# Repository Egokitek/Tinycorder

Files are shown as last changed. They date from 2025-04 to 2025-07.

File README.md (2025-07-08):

# Tinycorder (ES)

**(English below)**

## Un pequeño dispositivo multiuso con sensores

**Tinycorder** es un pequeño dispositivo multiuso que busca homenajear al mítico **tricorder** de la serie de ciencia ficción **Star Trek.**

Incluye varios sensores, asi como una pantalla de alta resolucion y bajo consumo que permite que lo usemos como badge electronico.

Es pequeño (75x85x10mm), ligero (70gr) y gasta muy poca energía.

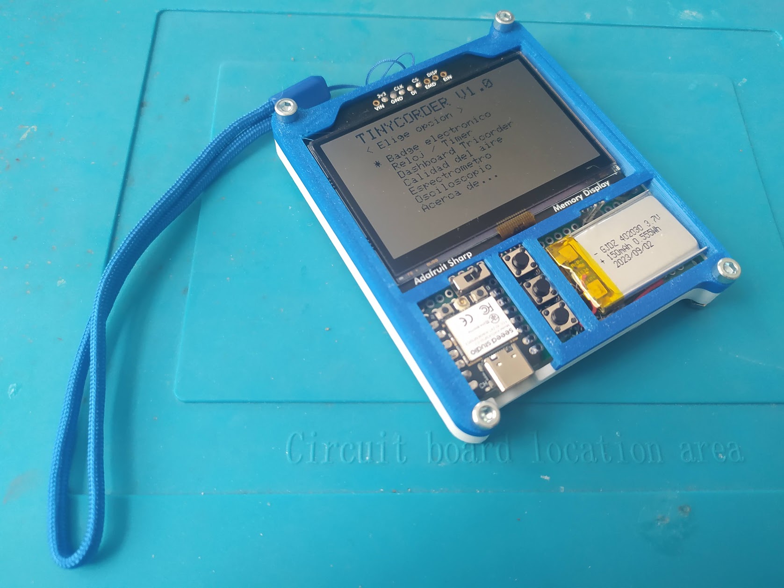
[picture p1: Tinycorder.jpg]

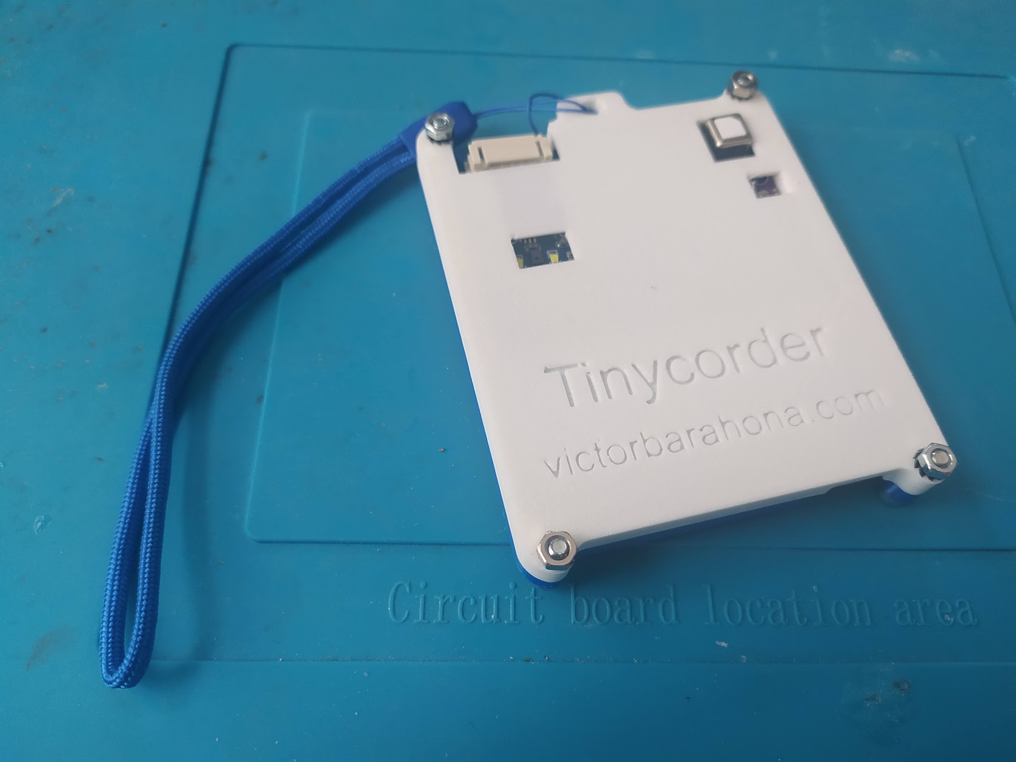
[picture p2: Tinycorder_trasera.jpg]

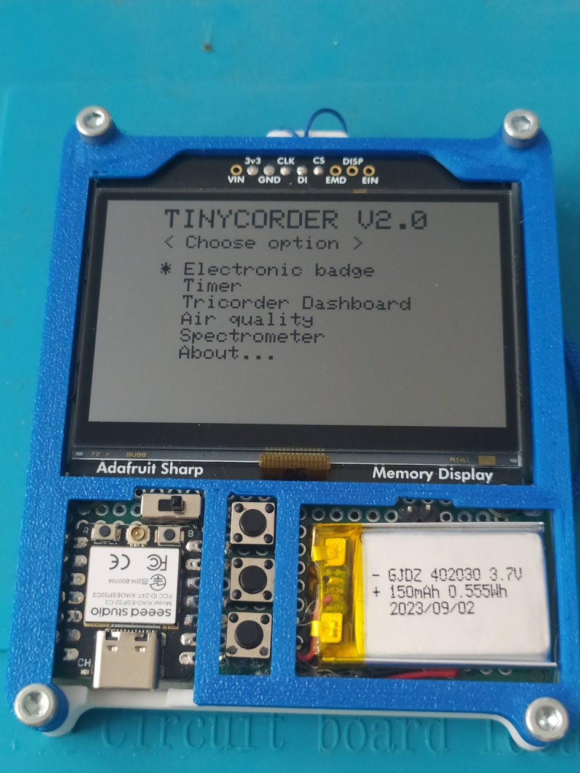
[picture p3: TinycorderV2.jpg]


## Características principales

- Chasis de dos piezas en PLA que se unen mediante 4 tornillos de M3x10.
- Incluye gancho para poderlo colgar del cuello o de la mano.
- MCU XIAO ESP32C3 de Seeed Studio.
- Batería Ion Litio de 150mAh.
- Interruptor de encendido y 3 pushbutton para interfaz (Up, Down, Enter).
- Pantalla Sharp Memory Display de 400x240px de Adafruit. Muy bajo consumo. 
- Sensor AS7341 para medición de luz en 7 bandas de visible y NIR (IR cercano).
- Sensor SCD40 para medición de calidad del aire y CO2.
- 2 pines libres accesibles desde frontal para medir señales analógicas.

## Algunas funciones ya en servicio

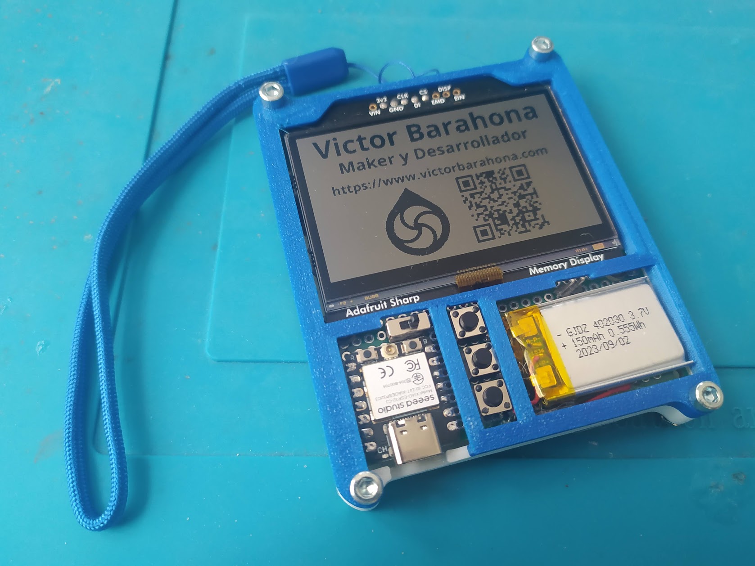
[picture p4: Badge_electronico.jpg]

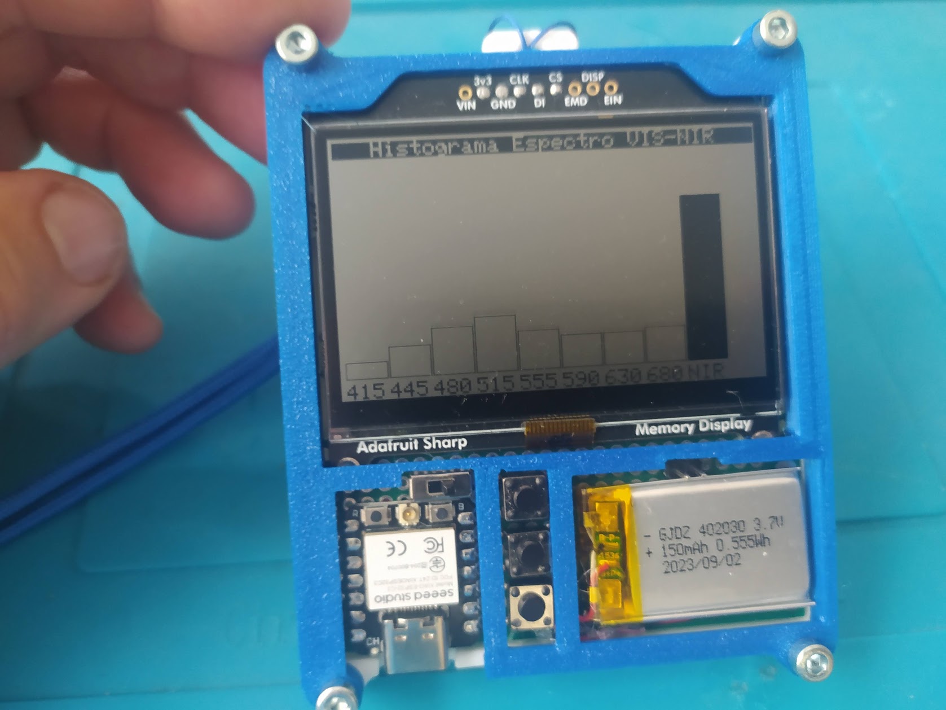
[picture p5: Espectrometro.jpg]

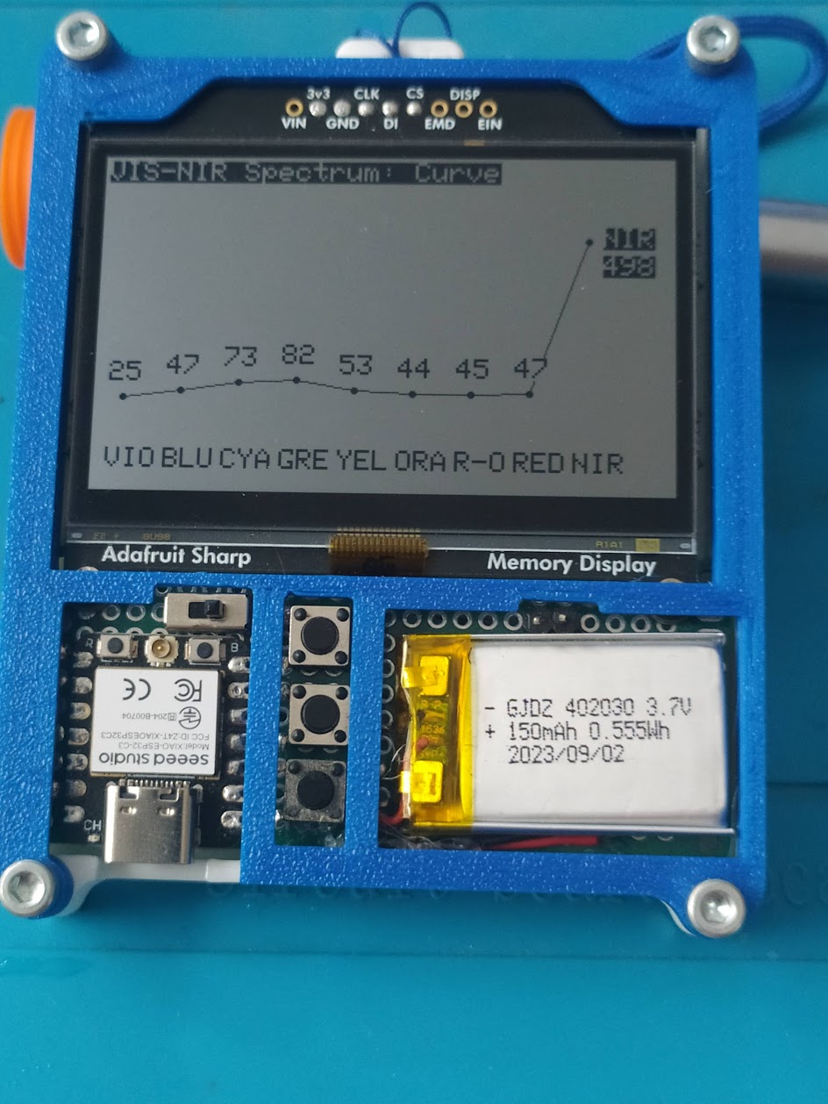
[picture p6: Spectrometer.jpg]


## Contenido de las carpetas

[**Montaje**](Montaje/README.md)

Proceso de montaje mediante fotos comentadas.

[**STLs**](STL/README.md)

Ficheros STL listos para imprimir.

[**SRC**](SRC/README.md)

Ficheros Arduino.

## Lista de componentes (BOM)

[BOM.xls](BOM.xlsx)

## Autor

Me llamo **Victor Barahona** y soy un ingeniero que ha sabido adaptarse a diferentes olas tecnológicas a lo largo de 30 años de carrera profesional. Tanto en el sector público como privado, tanto por cuenta ajena como de autónomo y emprendedor.

He trabajado en enseñanza, industria de automoción, telefonía móvil, impresión 3D, desarrollo de proyectos opensource y actualmente estoy en la empresa **I+Med** donde investigo en sistemas embebidos y Bioelectrónica.

Tengo varios hobbies, entre ellos la Permacultura. Soy también un maker entusiasta y construyo cosas como impresoras 3D o ARSandbox.

**Hago este tipo de proyectos en mi tiempo libre. Si te gustan y deseas apoyar que siga con ellos puedes donar o aportar en ko-fi:**



[**Mi cuenta Github**](https://github.com/Egokitek)

[Mi sitio web **www.victorbarahona.com**](http://www.victorbarahona.com)

## Créditos

Star Trek me inspiró para realizar este proyecto pero el diseño es totalmente propio.

## Licencia

GPL3.0

## Posibles mejoras

- Monitorear tension de batería y mostrarla mediante un indicador.
- Añadir funciones pendientes como tester/osciloscopio
- Nuevas funciones que se me vayan ocurriendo.

## Version 2 (actualizada el 6 de Julio de 2025)

**Se completa el código con los siguientes cambios:**

- Se completa la funcion de timer, permite ajustar bloques de 5 hasta 120 min. En el bloque de 25min aparece un mensaje de "Pomodoro Timer !". Al activar comienza cuenta atras y al terminar avisa con un rotulo intermitente en pantalla.
- Se completa el menu de Dashboard, que muestra medidas de CO2, temp y humedad en forma de histograma, con medidas cada 5 min hasta un total de 24 por cada variable. El tiempo entre muestras se puede cambiar en firmware para que tome un tiempo mas amplio de muestreo total.
- El menu "Calidad del aire" presenta medidas de CO2, temperatura y humedad cada 5 segundos de forma continua, hasta que vuelvas al menu principal.
- El menú "espectrómetro ya funcionaba pero se ha mejorado. Ahora puede mostrar el espectro en forma de histograma, lineas o numérico, se puede cambiar entre cualquiera de ellos o volver al menu principal.
- El menú "Acerca de" se ha mejorado en estética y presenta información básica.
- Se ha eliminado por el momento la función de osciloscopio. Quizás se aborde en el futuro.

**Cambios pendientes:**

- Añadir un buzzer pequeño para dar sonido al dispositivo.
- Añadir un sensor de tiempo de vuelo para medir distancia y quizas generar una especie de "sonar".
- Optimizar el consumo jugando mejor con los procesos de deep sleep.
- Opción de activar/desactivar LED para linterna, usando los que lleva el sensor de espectrómetro.
- Control de tensión de batería para ver autonomía en pantalla.
- Probar con otras pantallas mas economicas y rediseñar el hardware. La Sharp es muy buena pero es algo cara.
- **Importante** crear la PCB. Ahora es una perfboard ya que es un prototipo.
- ¿ Que mas .....?

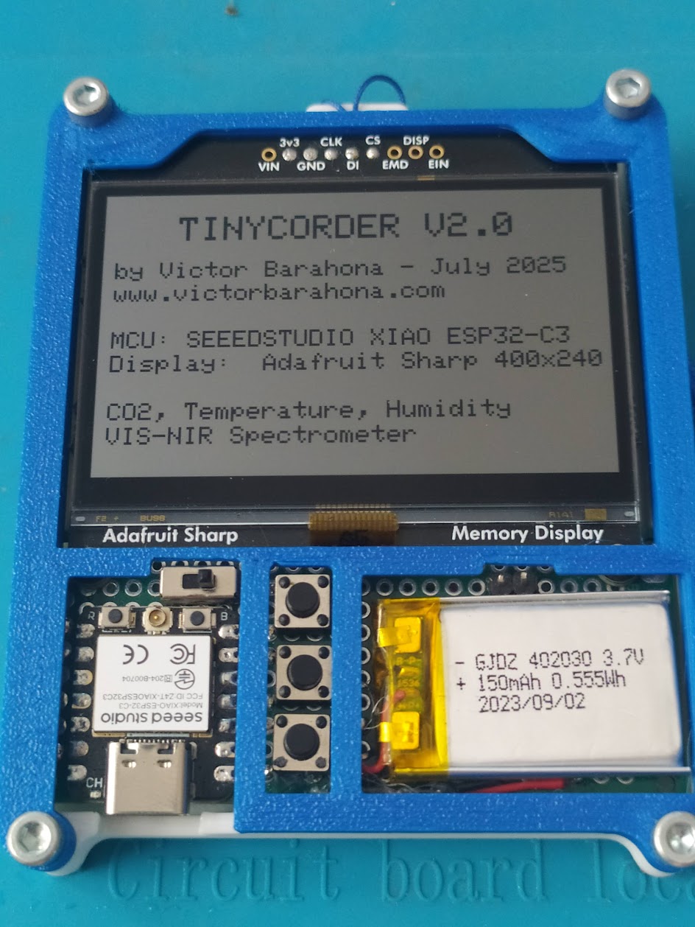
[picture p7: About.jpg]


---

# Tinycorder (EN)

## A small multi-purpose device with sensors

**Tinycorder** is a small multi-purpose device that pays homage to the legendary **tricorder** from the science fiction series **Star Trek.**

It includes several sensors, as well as a high-resolution, low-power display that allows it to be used as an electronic badge.

It is small (75x85x10mm), lightweight (70g), and consumes very little power.

## Main features

- Two-piece PLA chassis joined by 4 M3x10 screws.
- Includes a hook to hang it from your neck or hand.
- Seeed Studio XIAO ESP32C3 MCU.
- 150mAh Lithium-Ion battery.
- Power switch and 3 pushbuttons for interface (Up, Down, Enter).
- Adafruit Sharp Memory Display 400x240px. Very low power consumption.
- AS7341 sensor for measuring light in 7 visible and NIR (near IR) bands.
- SCD40 sensor for air quality and CO2 measurement.
- BMP280 sensor for temperature, humidity, and pressure measurement.
- 2 free pins accessible from the front to measure analog signals.

## Some functions already in service

Cyberdeck PICO8

## Folder contents

[**Assembly**](Montaje/README.md)

Assembly process with commented photos.

[**STLs**](STL/README.md)

Ready-to-print STL files.

[**SRC**](SRC/README.md)

Arduino files.

## Bill of Materials (BOM)

[BOM.xls](BOM.xlsx)

## Author

My name is **Victor Barahona** and I am an engineer who has adapted to different technological waves over 30 years of professional career. Both in the public and private sectors, as an employee, freelancer, and entrepreneur.

I have worked in education, automotive industry, mobile telephony, 3D printing, open source project development, and I am currently at **I+Med** where I research embedded systems and Bioelectronics.

I have several hobbies, including Permaculture. I am also an enthusiastic maker and build things like 3D printers or ARSandbox.

**I do these kinds of projects in my free time. If you like them and want to support me to continue, you can donate or contribute on ko-fi:**



[**My Github account**](https://github.com/Egokitek)

[My website **www.victorbarahona.com**](http://www.victorbarahona.com)

## Credits

Star Trek inspired me to make this project but the design is entirely my own.

## License

GPL3.0

## Possible improvements

- Monitor battery voltage and display it with an indicator.
- Add pending functions such as tester/oscilloscope
- New functions as they occur to me.

## Version 2 (updated July 6, 2025)

**The code is completed with the following changes:**

- The timer function is completed, allowing you to set blocks from 5 to 120 min. In the 25min block, a "Pomodoro Timer!" message appears. When activated, it starts a countdown and, when finished, notifies with a flashing label on the screen.
- The Dashboard menu is completed, showing CO2, temp, and humidity measurements as a histogram, with measurements every 5 min up to a total of 24 for each variable. The time between samples can be changed in firmware to take a longer total sampling time.
- The "Air Quality" menu presents CO2, temperature, and humidity measurements every 5 seconds continuously, until you return to the main menu.
- The "Spectrometer" menu was already working but has been improved. Now it can display the spectrum as a histogram, lines, or numeric; you can switch between any of them or return to the main menu.
- The "About" menu has been improved in appearance and presents basic information.
- The oscilloscope function has been removed for now. It may be addressed in the future.

**Pending changes:**

- Add a small buzzer to give sound to the device.
- Add a time-of-flight sensor to measure distance and perhaps generate a kind of "sonar".
- Optimize power consumption by better managing deep sleep processes.
- Option to enable/disable LED for flashlight, using those on the spectrometer sensor.
- Battery voltage control to see autonomy on screen.
- Try other, more economical displays and redesign the hardware. The Sharp is very good but somewhat expensive.
- **Important** create the PCB. It is currently a perfboard as it is a prototype.
- What else...?

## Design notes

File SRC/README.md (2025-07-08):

# Código Arduino
## (English below)

**En esta carpeta se contienen los ficheros necesarios del código Arduino.**

Contiene el fichero .ino principal y dos ficheros auxiliares:

- Badges.h
- Badges.cpp

Ambos sirven para la conversión del badge de jpg a código entendible por Arduino.

---

## Arduino Code

**This folder contains the necessary Arduino code files.**

It includes the main .ino file and two auxiliary files:

- Badges.h
- Badges.cpp

Both are used for converting the badge from jpg to code understandable by Arduino.

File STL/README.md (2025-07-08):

# STLs
## (English below)

**En esta carpeta se contienen los ficheros STL necesarios**

Puedes verlos con el visualizador integrado en Github o bien mediante programas como Cura, Repetier etc.

Contiene dos ficheros, la parte superior e inferior de la carcasa, que se unen mediante 4 tornillos de M3x10.

---

## STL Files

This folder contains the necessary STL files.

You can view them with the integrated viewer on Github or with programs such as Cura, Repetier, etc.

It contains two files, the top and bottom parts of the case, which are joined together with 4 M3x10 screws.

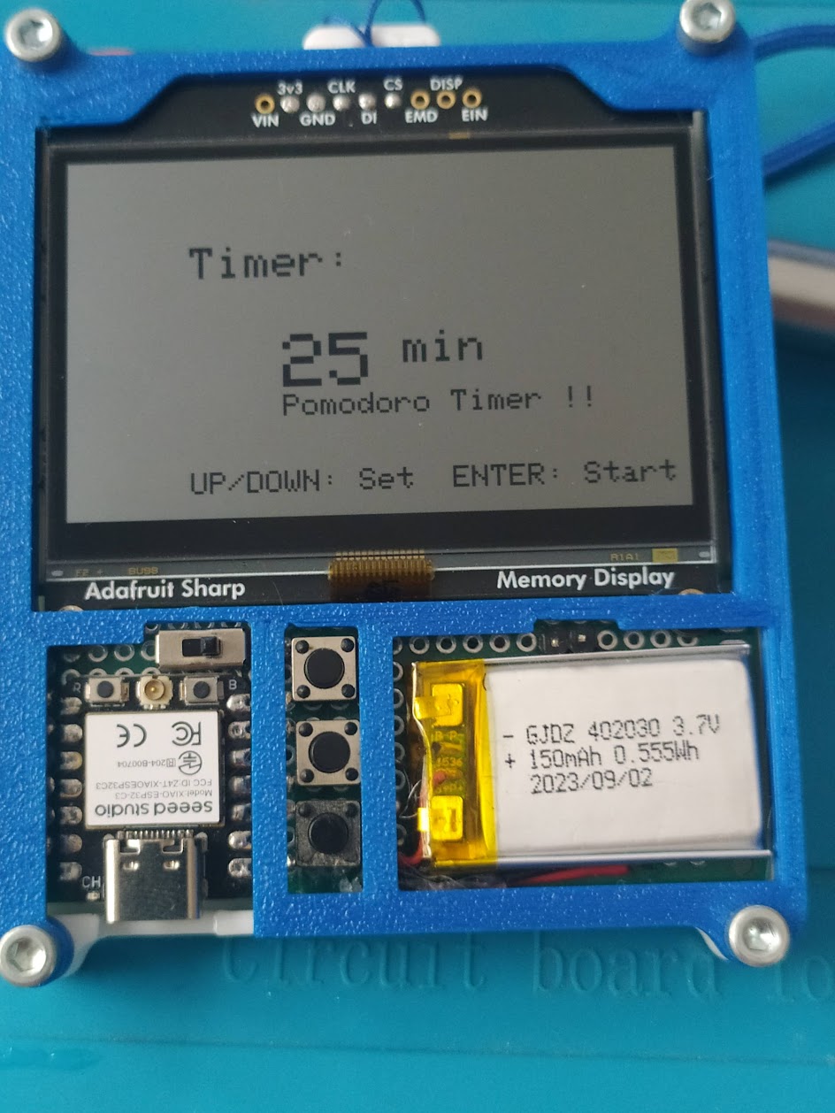
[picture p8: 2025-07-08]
Pomodoro.jpg

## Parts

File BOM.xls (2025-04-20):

Descripción | Componente | Cantidad | Coste EUR | Proveedor | Observaciones
Interruptor encendido | Toggle Switch | 1 | 0.05 | Amazon | Lote de 150 a 8eur
Li Ion 150mAh | LIPO-150mAh | 1 | Reciclada |  | Reciclada de teclado bluetooth
Pantalla Adafruit LCD | LCD 400x240px | 1 | 35 | Digikey | Sharp Memory Display
MCU ESP32C3 | XIAO ESP32C3 | 1 | 5 | Digikey | SEEED STUDIO XIAO ESP32C3
Pushbutton | Pushbutton | 3 | 0.05 | Amazon | Lote de 100 a unos 5eur
Sensor Temp, Hr, presion | BMP280 | 1 | 5 | Aliexpress
Sensor CO2 | SCD40 | 1 | 12 | Aliexpress
Sensor luz 8 bandas | AS7341 | 1 | 20 | Aliexpress

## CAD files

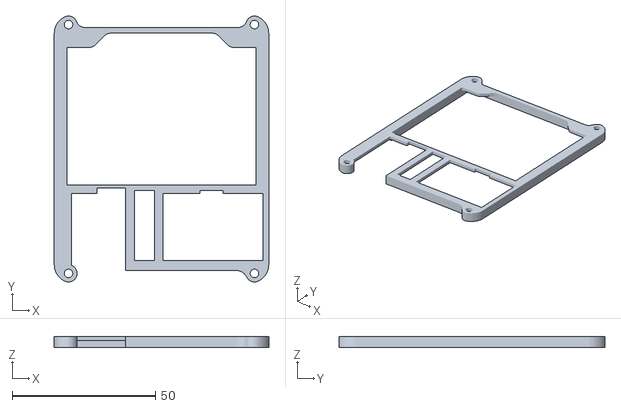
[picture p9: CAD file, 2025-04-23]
STL/Tinycorder Top.stl
75.0 x 93.0 x 4.00

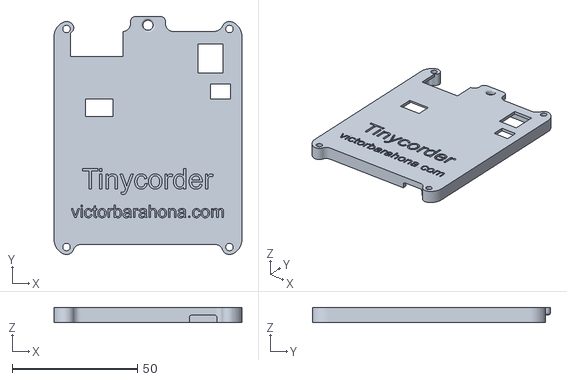
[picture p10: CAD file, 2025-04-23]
STL/Tinycorder Bottom.stl
75.0 x 95.0 x 6.00

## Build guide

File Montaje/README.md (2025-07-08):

# Montaje de Tinycorder
# (English below)

## Esquema del dispositivo:

ATENCION: Algunos componentes no se muestran como son realmente ya que Fritzing no los contiene en las librerías. Y puede haber algun error en la nomenclatura de los pines. Tomar la información de este montaje con precaución.

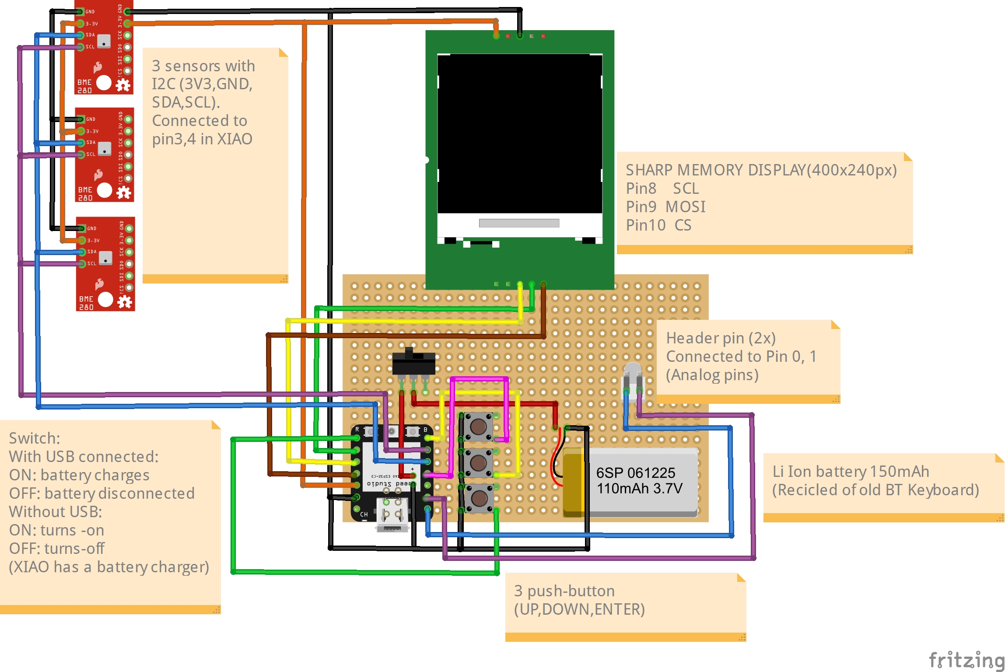
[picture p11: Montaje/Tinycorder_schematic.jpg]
Esquemático


## Montaje del dispositivo:

En esta imagen vemos los componentes que vamos a utilizar. La pantalla usa el bus SPI y los sensores el I2C, de solo dos pines.

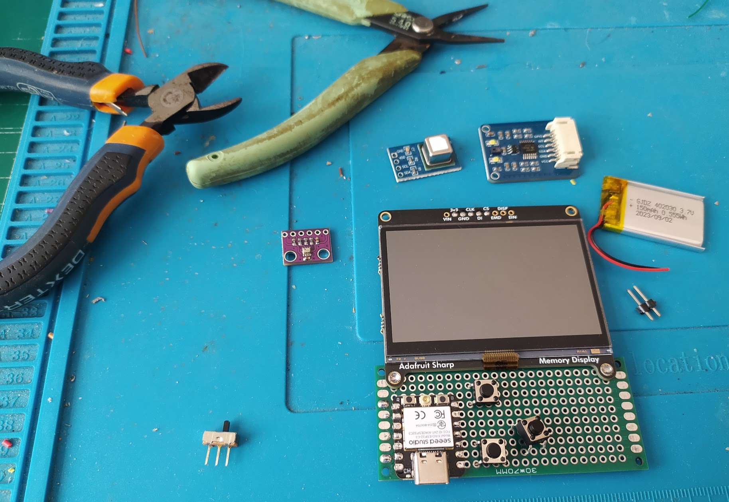
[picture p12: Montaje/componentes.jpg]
Componentes


Procedemos a soldar los componentes entre si.

En la perfboard soldamos el MCU, switch, 3 pushbutton y header de dos puntas. Para el XIAO alinear bien de tal forma que sus dos pad de bateria queden accesibles desde abajo, ya que aplicaremos una gota de soldadura y debe servir para que el circuito de control de la bateria funcione bien. Lo sabremos si al conectar el puerto USB tenemos unos 4V en esas dos conexiones. Si no lo tenemos hay que repasar la soldadura.

La perfboard la unimos al display con soldadura (tiene zonas metalicas donde el estaño agarra bien. Tambien puede hacerse con cola termofusible).

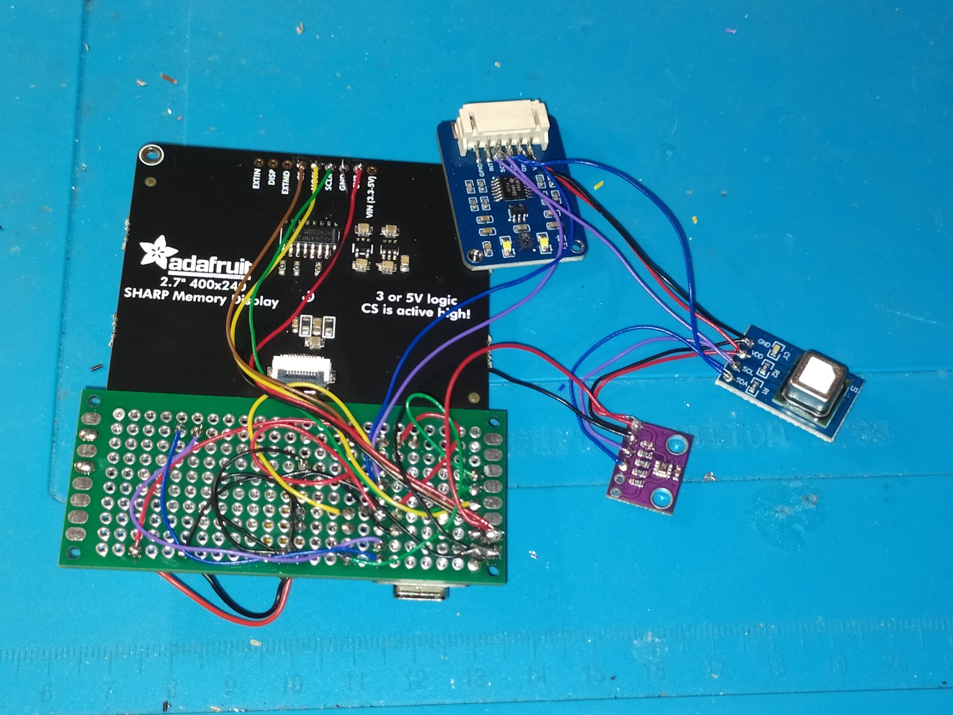
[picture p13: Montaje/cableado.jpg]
Cableado


La batería la pegaremos con cola termofusible, igualmente los sensores, aprovechando el espacio libre en la parte trasera del display que es plano.

**ATENCION: Diseñé las piezas en PLA después de este punto con las medidas tal y como coloqué los componentes. Si construyes una copia tendrás que hacerlo al revés. Imprimir las piezas y usarlas como guía para pegar os sensores, si no no te cabrán correctamente.**

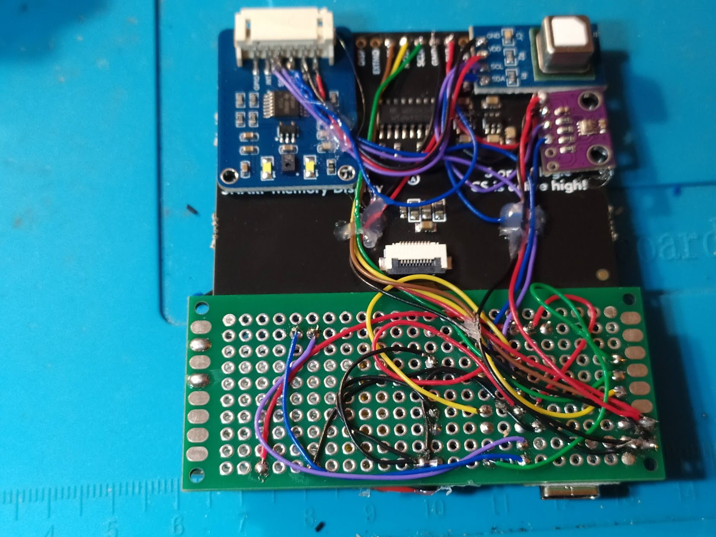
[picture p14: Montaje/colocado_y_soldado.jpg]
Montaje y soldadura


Una vez montado y cargado el software vemos el aspecto que tiene.

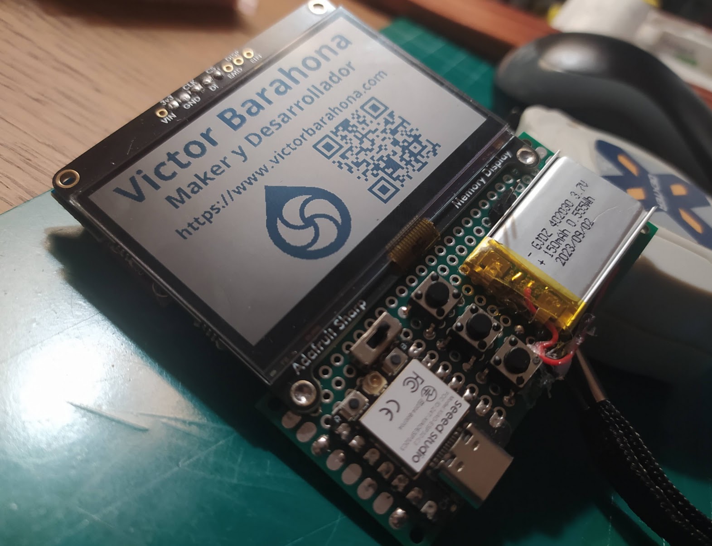
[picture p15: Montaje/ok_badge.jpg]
Prueba Badge


Y aquí como espectrómetro numérico, los valores se ven bajos porque el sensor está contra la mesa y no recibe luz.

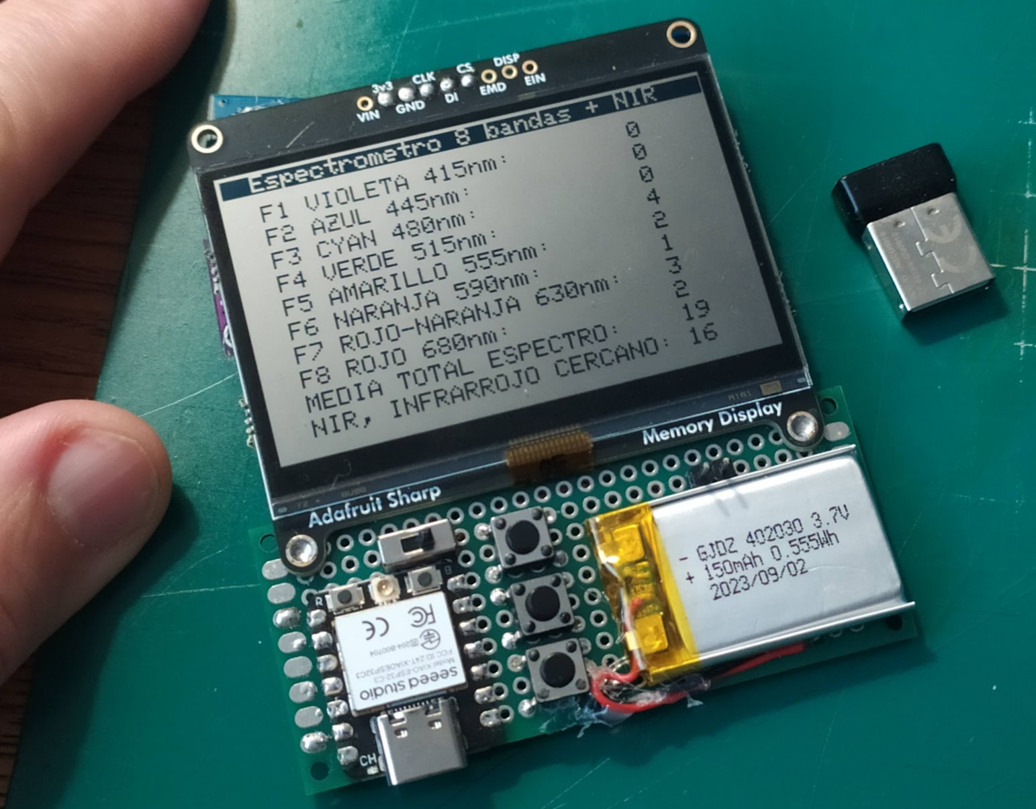
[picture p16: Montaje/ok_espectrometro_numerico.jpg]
Espectrómetro numérico


***

## Tinycorder Assembly

## Device schematic:

WARNING: Some components are not shown as they really are because Fritzing does not include them in its libraries. There may also be some errors in pin naming. Take the information from this assembly with caution.

Esquemático

## Device assembly:

In this image we see the components we are going to use. The display uses the SPI bus and the sensors use I2C, which only requires two pins.

Componentes

We proceed to solder the components together.

On the perfboard, solder the MCU, switch, 3 pushbuttons, and a two-pin header. For the XIAO, align it so that its two battery pads are accessible from below, as we will apply a drop of solder and it must allow the battery control circuit to work properly. We will know it works if, when connecting the USB port, we have about 4V on those two connections. If not, check the soldering.

Join the perfboard to the display with solder (it has metallic areas where the tin adheres well. It can also be done with hot glue).

Cableado

Glue the battery with hot glue, as well as the sensors, taking advantage of the free space on the back of the display, which is flat.

**WARNING: I designed the PLA parts after this point with the measurements as I placed the components. If you build a copy, you will have to do it the other way around: print the parts and use them as a guide to glue the sensors, otherwise they will not fit correctly.**

Montaje y soldadura

Once assembled and the software loaded, this is how it looks.

Prueba Badge

And here as a numeric spectrometer, the values appear low because the sensor is facing the table and does not receive light.

Espectrómetro numérico

***

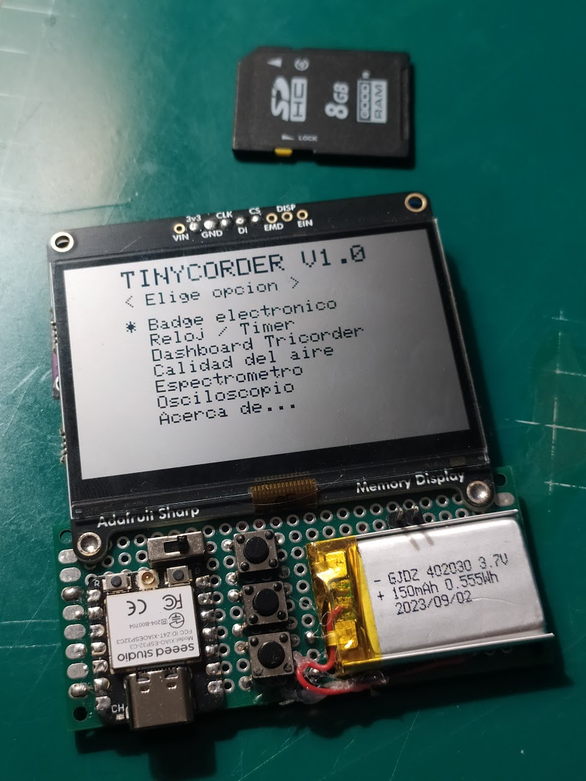
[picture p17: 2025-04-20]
Montaje/IMG_20250325_202723.jpg

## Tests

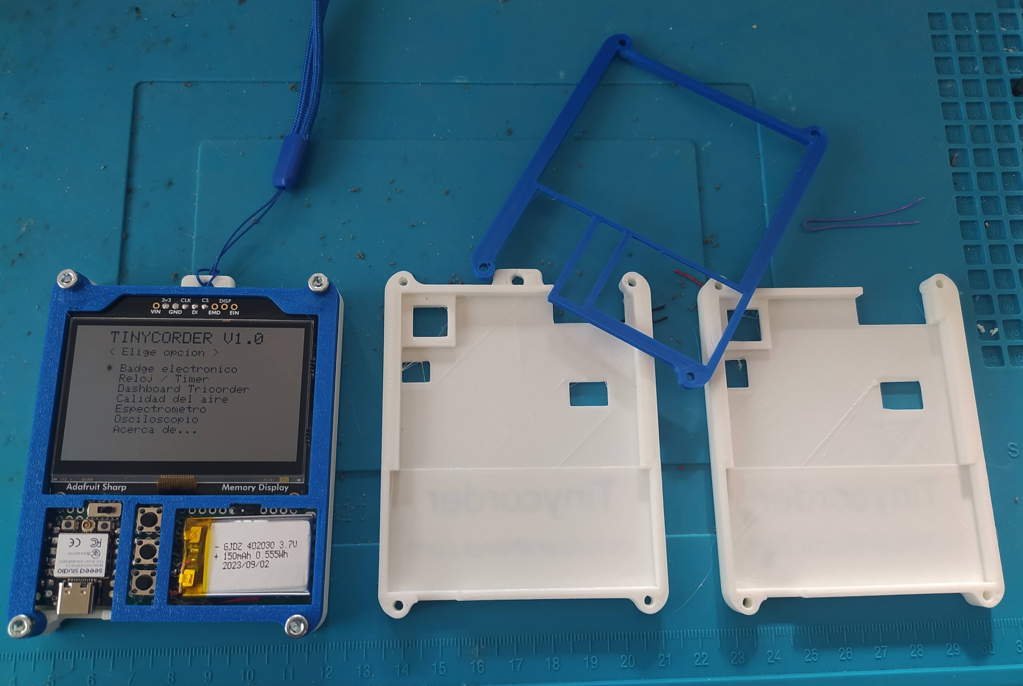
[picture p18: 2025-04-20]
Montaje/pruebas_carcasa.jpg

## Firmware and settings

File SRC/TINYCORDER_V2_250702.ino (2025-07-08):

///////////////////////////////////////////////////////////
///                  TINYCORDER V2.0                    ///
///////////////////////////////////////////////////////////
///                    MAIN PROGRAM                     ///
///////////////////////////////////////////////////////////
///            Victor Barahona - July 2025              ///
///               www.victorbarahona.com                ///
///////////////////////////////////////////////////////////

/*  TINYCORDER: UN TRICORDER BASADO EN EL ADAFRUIT SHARP MEMORY DISPLAY DE 400x240px */

#include <Arduino.h>
#include <esp_sleep.h>
#include <Adafruit_SharpMem.h>  //Librería especifica Pantalla 400x240 de Adafruit
#include <Adafruit_AS7341.h>    //Sensor espectrometro
#include "Adafruit_GFX.h"       //Librería gráfica Adafruit
#include <SPI.h>                //La pantalla necesita bus SPI
#include <Wire.h>               //Para tareas que requieren bus I2C
#include <SensirionI2CScd4x.h>  //Libreria sensor CO2, temp, humedad


#include "Badges.h"  //Contiene los badges que voy implementando de forma personalizada

// any pins can be used
#define SHARP_SCK 8
#define SHARP_MOSI 9
#define SHARP_SS 10

#define ANCHO 400
#define ALTO 240
#define BLACK 0
#define WHITE 1

//Adafruit_SharpMem display(SHARP_SCK, SHARP_MOSI, SHARP_SS, 144, 168);
Adafruit_SharpMem display(SHARP_SCK, SHARP_MOSI, SHARP_SS, ANCHO, ALTO);
int minorHalfSize;  // 1/2 of lesser of display width or height

//Instanciar clase sensor CO2
SensirionI2CScd4x scd4x;

void printUint16Hex(uint16_t value) {
  Serial.print(value < 4096 ? "0" : "");
  Serial.print(value < 256 ? "0" : "");
  Serial.print(value < 16 ? "0" : "");
  Serial.print(value, HEX);
}

void printSerialNumber(uint16_t serial0, uint16_t serial1, uint16_t serial2) {
  Serial.print("Serial: 0x");
  printUint16Hex(serial0);
  printUint16Hex(serial1);
  printUint16Hex(serial2);
  Serial.println();
}

// --- PARAMETRIZACIÓN DE IDIOMA --- // --- LANGUAGE PARAMETERIZATION ---
enum Idioma { ESPANOL, INGLES }; // Idioma actual // Current language
Idioma idiomaActual = INGLES; // Cambia a ESPANOL si lo prefieres // Change to ESPANOL if you prefer
void setIdioma(Idioma idioma); // Prototipo necesario para evitar error de compilación // Prototype needed to avoid compilation error

//Botones para controlar el dispositivo // Buttons to control the device
#define BUTTON_UP 5       // Cable Rojo, pin 3, gpio 5 // Red wire, pin 3, gpio 5
#define BUTTON_DOWN 21    // Cable amarillo, pin 6, gpio 21 // Yellow wire, pin 6, gpio 21
#define BUTTON_ENTER 20   // Cable verde, pin 7, gpio 20 // Green wire, pin 7, gpio 20
#define DEBOUNCE_TIME 50  // Tiempo de debounce en ms // Debounce time in ms

unsigned long lastDebounceTimeUP = 0;
unsigned long lastDebounceTimeDOWN = 0;
unsigned long lastDebounceTimeENTER = 0;
bool lastStateUP = HIGH;
bool lastStateDOWN = HIGH;
bool lastStateENTER = HIGH;
bool currentStateUP = HIGH;
bool currentStateDOWN = HIGH;
bool currentStateENTER = HIGH;

const char *menus_es[] = { "Badge electronico", "Timer", "Dashboard Tricorder", "Calidad del aire", "Espectrometro", "Acerca de..." }; // Menú en español // Menu in Spanish
const char *menus_en[] = { "Electronic badge", "Timer", "Tricorder Dashboard", "Air quality", "Spectrometer", "About..." }; // Menú en inglés // Menu in English
const char **menus = menus_en; // Por defecto inglés // Default to English
const int totalMenus = 6;
int menuIndex = 0;
bool menuSelected = false;
unsigned long lastButtonPress = 0;

/* Definición de la clase para el sensor AS7341, espectrometro de 8 bandas mas NIR */
/* Definition of the class for the AS7341 sensor, 8-band spectrometer plus NIR */
Adafruit_AS7341 as7341;

// --- DASHBOARD: HISTÓRICO DE 24 MEDIDAS ---
#define DASHBOARD_HISTORY 24
unsigned long dashboard_interval_ms = 5UL * 60UL * 1000UL; // Intervalo de muestreo en ms (por defecto 5 minutos)
uint16_t co2_history[DASHBOARD_HISTORY] = {0};
float temp_history[DASHBOARD_HISTORY] = {0};
float hum_history[DASHBOARD_HISTORY] = {0};
uint8_t dashboard_index = 0;
uint8_t dashboard_count = 0;
unsigned long dashboard_last_update = 0;

void setup() {
  Serial.begin(115200);
  display.begin();
  Wire.begin();

  //while (!Serial) {
  //  delay(100);
  //}

  uint16_t error;
  char errorMessage[256];
  scd4x.begin(Wire);

  // stop potentially previously started measurement // Detener medición previa si existe
  error = scd4x.stopPeriodicMeasurement();
  if (error) {
    Serial.print("Error trying to execute stopPeriodicMeasurement(): ");
    errorToString(error, errorMessage, 256);
    Serial.println(errorMessage);
  }

  uint16_t serial0;
  uint16_t serial1;
  uint16_t serial2;
  error = scd4x.getSerialNumber(serial0, serial1, serial2);
  if (error) {
    Serial.print("Error trying to execute getSerialNumber(): ");
    errorToString(error, errorMessage, 256);
    Serial.println(errorMessage);
  } else {
    printSerialNumber(serial0, serial1, serial2);
  }

  // Start Measurement // Iniciar medición
  error = scd4x.startPeriodicMeasurement();
  if (error) {
    Serial.print("Error trying to execute startPeriodicMeasurement(): ");
    errorToString(error, errorMessage, 256);
    Serial.println(errorMessage);
  }

  Serial.println("Waiting for first measurement... (5 sec)"); // Esperando primera medición

  //setup de botones y su tiempo de rebote // Button setup and debounce time
  pinMode(BUTTON_UP, INPUT_PULLUP);     // Activa la resistencia pull-up interna // Enable internal pull-up resistor
  pinMode(BUTTON_DOWN, INPUT_PULLUP);   // Activa la resistencia pull-up interna // Enable internal pull-up resistor
  pinMode(BUTTON_ENTER, INPUT_PULLUP);  // Activa la resistencia pull-up interna // Enable internal pull-up resistor

  display.clearDisplay();  // clears the screen and buffer // Limpia la pantalla y el buffer

  // Several shapes are drawn centered on the screen.  Calculate 1/2 of
  // lesser of display width or height, this is used repeatedly later.
  // Varias formas se dibujan centradas en la pantalla. Calcula 1/2 del menor de ancho o alto, se usa repetidamente.
  minorHalfSize = min(display.width(), display.height()) / 2;

  if (!as7341.begin()) {
    Serial.println("Could not find AS7341"); // No se pudo encontrar el AS7341
    while (1) { delay(10); }
  }

  as7341.setATIME(100);
  as7341.setASTEP(999);
  as7341.setGain(AS7341_GAIN_256X);

  drawMenu();
}

void loop() {
  display.setRotation(0);
  showMenu();
}


void checkButtons() {
  unsigned long currentMillis = millis();

  // --- Debounce para BUTTON_UP  ---
  bool readingUP = digitalRead(BUTTON_UP);
  if (readingUP != lastStateUP) {
    lastDebounceTimeUP = currentMillis;
  }
  if ((currentMillis - lastDebounceTimeUP) > DEBOUNCE_TIME) {
    if (readingUP == LOW && currentStateUP == HIGH) {
      menuIndex = (menuIndex - 1 + totalMenus) % totalMenus;
      drawMenu();
    }
    currentStateUP = readingUP;
  }
  lastStateUP = readingUP;

  // --- Debounce para BUTTON_DOWN  ---
  bool readingDOWN = digitalRead(BUTTON_DOWN);
  if (readingDOWN != lastStateDOWN) {
    lastDebounceTimeDOWN = currentMillis;
  }
  if ((currentMillis - lastDebounceTimeDOWN) > DEBOUNCE_TIME) {
    if (readingDOWN == LOW && currentStateDOWN == HIGH) {
      menuIndex = (menuIndex + 1) % totalMenus;
      drawMenu();
    }
    currentStateDOWN = readingDOWN;
  }
  lastStateDOWN = readingDOWN;

  // --- Debounce para BUTTON_ENTER  ---
  bool readingENTER = digitalRead(BUTTON_ENTER);
  if (readingENTER != lastStateENTER) {
    lastDebounceTimeENTER = currentMillis;
  }
  if ((currentMillis - lastDebounceTimeENTER) > DEBOUNCE_TIME) {
    if (readingENTER == LOW && currentStateENTER == HIGH) {
      executeTask(menuIndex);
      drawMenu(); // Volver al menú en la misma posición
    }
    currentStateENTER = readingENTER;
  }
  lastStateENTER = readingENTER;
}

void drawMenu() {
  display.clearDisplay();
  display.setTextSize(3);
  display.setTextColor(BLACK);
  display.setCursor(60, 10);
  display.println("TINYCORDER V2.0");
  display.setCursor(60, 40);
  display.setTextSize(2);
  display.println(idiomaActual == ESPANOL ? "< Elige opcion >" : "< Choose option >");

  for (int i = 0; i < totalMenus; i++) {
    display.setCursor(60, 70 + (i * 18));  // Espaciado vertical entre opciones

    if (i == menuIndex) {
      display.print("* ");  // Asterisco para la opción seleccionada
    } else {
      display.print("  ");  // Espacio en las demás opciones
    }

    display.println(menus[i]);  // Mostrar nombre del menú
  }

  display.refresh();
  delay(50);
}

// --- PARAMETRIZACIÓN DE IDIOMA ---
//enum Idioma { ESPANOL, INGLES };
//Idioma idiomaActual = INGLES; // Cambia a ESPANOL si lo prefieres
void setIdioma(Idioma idioma) {
  idiomaActual = idioma;
  menus = (idioma == ESPANOL) ? menus_es : menus_en;
}

void executeTask(int index) {
  display.clearDisplay();
  display.setCursor(60, 200);
  display.setTextSize(1);
  display.setTextColor(BLACK);

  switch (index) {
    case 0:
      badge();
      break;
    case 1:
      timer();
      break;
    case 2:
      dashboard();
      break;
    case 3:
      calidad_aire();
      break;
    case 4:
      espectrometro();
      break;
    case 5:
      acercade();
      break;
  }

  display.refresh();
  delay(2000);  // Mantener el mensaje 2 segundos antes de volver al menú
}



void badge() {
  display.setTextColor(BLACK);
  //Muestra Badge personal
  display.drawBitmap(0, 0, vj_personal_badge, 400, 240, WHITE, BLACK);
  display.refresh();
  esp_deep_sleep_start();

}


// --- MENÚ ESPECTRÓMETRO: SELECCIÓN DIRECTA ---
void espectrometro() {
  int modo = 0;
  bool seleccionando = true;
  // Esperar a que todos los botones estén soltados antes de mostrar el menú
  while (digitalRead(BUTTON_UP) == LOW || digitalRead(BUTTON_DOWN) == LOW || digitalRead(BUTTON_ENTER) == LOW) {
    delay(10);
  }
  while (seleccionando) {
    display.clearDisplay();
    display.setTextSize(3);
    display.setCursor(60, 40);
    display.setTextColor(BLACK);
    display.println("Spectrometer:");
    display.setTextSize(2);
    display.setCursor(60, 90);
    display.print(modo == 0 ? "> " : "  "); display.println("Histogram");
    display.setCursor(60, 120);
    display.print(modo == 1 ? "> " : "  "); display.println("Curve");
    display.setCursor(60, 150);
    display.print(modo == 2 ? "> " : "  "); display.println("Data");
    display.refresh();
    // Navegación
    bool salir = false;
    while (!salir) {
      if (digitalRead(BUTTON_UP) == LOW) { modo = (modo + 2) % 3; delay(200); salir = true; }
      else if (digitalRead(BUTTON_DOWN) == LOW) { modo = (modo + 1) % 3; delay(200); salir = true; }
      else if (digitalRead(BUTTON_ENTER) == LOW) { delay(200); seleccionando = false; salir = true; }
      delay(10);
    }
    // Esperar a que se suelten todos los botones antes de permitir otra navegación
    while (digitalRead(BUTTON_UP) == LOW || digitalRead(BUTTON_DOWN) == LOW || digitalRead(BUTTON_ENTER) == LOW) {
      delay(10);
    }
  }
  // Ejecutar modo seleccionado
  switch (modo) {
    case 0: espectro_histograma(); break;
    case 1: espectro_grafica(); break;
    case 2: espectro_numerico(); break;
  }
}

// --- TIMER: AJUSTE Y CUENTA ATRÁS ---
void timer() {
  int minutos = 5;
  bool ajustando = true;
  // Esperar a que todos los botones estén soltados antes de mostrar el menú
  while (digitalRead(BUTTON_UP) == LOW || digitalRead(BUTTON_DOWN) == LOW || digitalRead(BUTTON_ENTER) == LOW) {
    delay(10);
  }
  while (ajustando) {
    display.clearDisplay();
    display.setTextSize(3);
    display.setCursor(80, 60);
    display.setTextColor(BLACK);
    display.print(idiomaActual == ESPANOL ? "Temporizador:" : "Timer:");
    display.setCursor(140, 120);
    display.setTextSize(5);
    display.print(minutos);
    display.setTextSize(3);
    display.print(" min");
    if (minutos == 25) {
      display.setTextSize(2);
      display.setCursor(140, 160);
      display.setTextColor(BLACK);
      display.print("Pomodoro Timer !!");
    }
    display.setTextSize(2);
    display.setCursor(80, 210);
    display.print(idiomaActual == ESPANOL ? "UP/DOWN: Ajustar  ENTER: Iniciar" : "UP/DOWN: Set  ENTER: Start");
    display.refresh();
    // Ajuste de minutos
    bool salir = false;
    while (!salir) {
      if (digitalRead(BUTTON_UP) == LOW) {
        minutos += 5;
        if (minutos > 120) minutos = 5;
        delay(200);
        salir = true;
      }
      if (digitalRead(BUTTON_DOWN) == LOW) {
        minutos -= 5;
        if (minutos < 5) minutos = 120;
        delay(200);
        salir = true;
      }
      if (digitalRead(BUTTON_ENTER) == LOW) {
        ajustando = false;
        delay(200);
        salir = true;
      }
      delay(10);
    }
    // Esperar a que se suelten todos los botones antes de permitir otra navegación
    while (digitalRead(BUTTON_UP) == LOW || digitalRead(BUTTON_DOWN) == LOW || digitalRead(BUTTON_ENTER) == LOW) {
      delay(10);
    }
  }
  // Cuenta atrás sin deep sleep, solo delay y refresco
  while (minutos > 0) {
    display.clearDisplay();
    display.setTextSize(4);
    display.setCursor(150, 80);
    display.setTextColor(BLACK);
    display.print(minutos);
    display.setTextSize(2);
    display.setCursor(170, 140);
    display.print("min");
    display.setTextSize(2);
    display.setCursor(100, 180);
    display.print(idiomaActual == ESPANOL ? "Cuenta atras..." : "Counting down...");
    display.refresh();
    for (int s = 0; s < 60; s++) {
      delay(1000); // 1 segundo
      // Permitir salir con botón
      if (digitalRead(BUTTON_ENTER) == LOW || digitalRead(BUTTON_DOWN) == LOW || digitalRead(BUTTON_UP) == LOW) {
        delay(200);
        return;
      }
    }
    minutos--;
  }
  // Al llegar a cero, parpadeo círculo centrado
  int circleState = 0;
  int cx = ANCHO / 2;
  int cy = ALTO / 2;
  int r = 50;
  while (true) {
    display.clearDisplay();
    if (circleState % 2 == 0) {
      display.fillCircle(cx, cy, r, BLACK);
      display.drawCircle(cx, cy, r, WHITE);
    } else {
      display.fillCircle(cx, cy, r, WHITE);
      display.drawCircle(cx, cy, r, BLACK);
    }
    display.setTextSize(3);
    display.setTextColor(circleState % 2 == 0 ? WHITE : BLACK);
    display.setCursor(cx - 40, cy - 20);
    display.print(idiomaActual == ESPANOL ? "FIN" : "END");
    display.setTextSize(2);
    display.setCursor(cx - 60, cy + 40);
    display.print(idiomaActual == ESPANOL ? "Pulsa boton" : "Press button");
    display.refresh();
    for (int t = 0; t < 100; t++) {
      if (digitalRead(BUTTON_ENTER) == LOW || digitalRead(BUTTON_DOWN) == LOW || digitalRead(BUTTON_UP) == LOW) {
        delay(200);
        return;
      }
      delay(10);
    }
    circleState++;
  }
}

void dashboard() {
  // --- Nuevo dashboard: 3 histogramas, autoescalado, sin leyendas ni min/max ---
  while (true) {
    unsigned long now = millis();
    if (dashboard_count == 0 || now - dashboard_last_update >= dashboard_interval_ms) {
      uint16_t error;
      char errorMessage[256];
      uint16_t co2 = 0;
      float temperature = 0.0f;
      float humidity = 0.0f;
      bool isDataReady = false;
      error = scd4x.getDataReadyFlag(isDataReady);
      if (!error && isDataReady) {
        error = scd4x.readMeasurement(co2, temperature, humidity);
      }
      co2_history[dashboard_index] = co2;
      temp_history[dashboard_index] = temperature;
      hum_history[dashboard_index] = humidity;
      dashboard_index = (dashboard_index + 1) % DASHBOARD_HISTORY;
      if (dashboard_count < DASHBOARD_HISTORY) dashboard_count++;
      dashboard_last_update = now;
    }
    display.clearDisplay();
    // Título
    display.setTextSize(3);
    display.setTextColor(BLACK);
    display.setCursor(120, 5);
    display.print("Dashboard");
    int n = dashboard_count;
    int start = (dashboard_index + DASHBOARD_HISTORY - n) % DASHBOARD_HISTORY;
    int x0 = 70, w = 300, bar_w = 10, sep = 3;
    // --- CO2 ---
    int y0 = 60, h = 40;
    display.setTextSize(2);
    display.setCursor(10, y0 - 20);
    display.print("CO2");
    uint16_t co2_min = 10000, co2_max = 0;
    for (int i = 0; i < n; i++) {
      int idx = (start + i) % DASHBOARD_HISTORY;
      if (co2_history[idx] < co2_min) co2_min = co2_history[idx];
      if (co2_history[idx] > co2_max) co2_max = co2_history[idx];
    }
    if (co2_min == co2_max) { co2_min -= 10; co2_max += 10; }
    // Eje X
    display.drawLine(x0, y0, x0 + w, y0, BLACK);
    for (int i = 0; i < n; i++) {
      int idx = (start + i) % DASHBOARD_HISTORY;
      int bar_h = (co2_max > co2_min) ? (int)((co2_history[idx] - co2_min) * h / (co2_max - co2_min)) : 0;
      int x = x0 + i * (bar_w + sep);
      display.fillRect(x, y0 - bar_h, bar_w, bar_h, WHITE);
      display.drawRect(x, y0 - bar_h, bar_w, bar_h, BLACK);
      display.setTextSize(1);
      display.setTextColor(BLACK);
      display.setCursor(x, y0 - bar_h - 12);
      display.print(co2_history[idx]);
    }
    // --- TEMP ---
    y0 = 120; h = 40;
    display.setTextSize(2);
    display.setCursor(10, y0 - 20);
    display.print("Temp");
    float temp_min = 1000, temp_max = -1000;
    for (int i = 0; i < n; i++) {
      int idx = (start + i) % DASHBOARD_HISTORY;
      if (temp_history[idx] < temp_min) temp_min = temp_history[idx];
      if (temp_history[idx] > temp_max) temp_max = temp_history[idx];
    }
    if (temp_min == temp_max) { temp_min -= 1; temp_max += 1; }
    display.drawLine(x0, y0, x0 + w, y0, BLACK);
    for (int i = 0; i < n; i++) {
      int idx = (start + i) % DASHBOARD_HISTORY;
      int bar_h = (temp_max > temp_min) ? (int)((temp_history[idx] - temp_min) * h / (temp_max - temp_min)) : 0;
      int x = x0 + i * (bar_w + sep);
      display.fillRect(x, y0 - bar_h, bar_w, bar_h, WHITE);
      display.drawRect(x, y0 - bar_h, bar_w, bar_h, BLACK);
      display.setTextSize(1);
      display.setTextColor(BLACK);
      display.setCursor(x, y0 - bar_h - 12);
      display.print(temp_history[idx], 1);
    }
    // --- HUM ---
    y0 = 180; h = 40;
    display.setTextSize(2);
    display.setCursor(10, y0 - 20);
    display.print("Hum");
    float hum_min = 1000, hum_max = -1000;
    for (int i = 0; i < n; i++) {
      int idx = (start + i) % DASHBOARD_HISTORY;
      if (hum_history[idx] < hum_min) hum_min = hum_history[idx];
      if (hum_history[idx] > hum_max) hum_max = hum_history[idx];
    }
    if (hum_min == hum_max) { hum_min -= 1; hum_max += 1; }
    display.drawLine(x0, y0, x0 + w, y0, BLACK);
    for (int i = 0; i < n; i++) {
      int idx = (start + i) % DASHBOARD_HISTORY;
      int bar_h = (hum_max > hum_min) ? (int)((hum_history[idx] - hum_min) * h / (hum_max - hum_min)) : 0;
      int x = x0 + i * (bar_w + sep);
      display.fillRect(x, y0 - bar_h, bar_w, bar_h, WHITE);
      display.drawRect(x, y0 - bar_h, bar_w, bar_h, BLACK);
      display.setTextSize(1);
      display.setTextColor(BLACK);
      display.setCursor(x, y0 - bar_h - 12);
      display.print(hum_history[idx], 1);
    }
    display.setTextSize(2);
    display.setCursor(10, 200);
    display.print("Samples every 5 min, 24 records");
    display.refresh();
    // Salir si se pulsa cualquier botón
    for (int t = 0; t < 300; t++) {
      if (digitalRead(BUTTON_ENTER) == LOW || digitalRead(BUTTON_DOWN) == LOW || digitalRead(BUTTON_UP) == LOW) {
        delay(200);
        return;
      }
      delay(10);
    }
  }
}

// --- CALIDAD DEL AIRE: VALORES EN TIEMPO REAL ---
void calidad_aire() {
  // Muestra valores en tiempo real cada 5 segundos
  while (true) {
    uint16_t co2 = 0;
    float temperature = 0.0f;
    float humidity = 0.0f;
    bool isDataReady = false;
    uint16_t error = scd4x.getDataReadyFlag(isDataReady);
    if (!error && isDataReady) {
      error = scd4x.readMeasurement(co2, temperature, humidity);
    }
    display.clearDisplay();
    // Marco general
    display.drawRect(40, 20, 320, 200, BLACK);
    // Marco para título
    display.fillRect(60, 30, 280, 40, WHITE);
    display.drawRect(60, 30, 280, 40, BLACK);
    display.setTextSize(3);
    display.setCursor(70, 38);
    display.setTextColor(BLACK);
    display.print(idiomaActual == ESPANOL ? "Calidad del aire" : "Air quality");
    // Marco para CO2
    display.drawRect(60, 85, 280, 35, BLACK);
    display.setTextSize(2);
    display.setCursor(80, 92);
    display.print("CO2: "); display.print(co2); display.print(" ppm");
    // Marco para Temp
    display.drawRect(60, 125, 280, 35, BLACK);
    display.setCursor(80, 132);
    display.print(idiomaActual == ESPANOL ? "Temp: " : "Temp: "); display.print(temperature, 1); display.print("C");
    // Marco para Humedad
    display.drawRect(60, 165, 280, 35, BLACK);
    display.setCursor(80, 172);
    display.print(idiomaActual == ESPANOL ? "Humedad: " : "Hum: "); display.print(humidity, 1); display.print("%");
    display.refresh();
    // Espera 5 segundos o hasta pulsación NUEVA de botón
    unsigned long t0 = millis();
    bool botonSoltado = false;
    // Esperar a que todos los botones estén soltados antes de empezar a contar
    while (digitalRead(BUTTON_ENTER) == LOW || digitalRead(BUTTON_DOWN) == LOW || digitalRead(BUTTON_UP) == LOW) {
      delay(10);
    }
    while (millis() - t0 < 5000) {
      if (digitalRead(BUTTON_ENTER) == LOW || digitalRead(BUTTON_DOWN) == LOW || digitalRead(BUTTON_UP) == LOW) {
        delay(200);
        return;
      }
      delay(10);
    }
  }
}
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

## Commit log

2025-04-20 Primera revision
    [BOM.xls, Bisel pantalla.stl, Cyberdeck_oct23_V2_Tapa.stl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]
2025-04-23 Actualización montaje, src, stls
    [Tinycorder Bottom.stl, Tinycorder Top.stl]
